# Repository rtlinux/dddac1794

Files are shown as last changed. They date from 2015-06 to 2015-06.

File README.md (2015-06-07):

# dddac1794
Eagle PCB files for the [DDDAC1794](http://www.dddac.com/dddac1794.html).

The motherboard designed by Doede Douma is very large and uses excessive amounts of space.

My design was made in order to keep the cost of the PCBs down and make it easier to produce the PCBs by hand.

## I2S Data Shifter

[OSH Park project](https://oshpark.com/shared_projects/d8tB1U43).

[Mouser project](http://www.mouser.com/ProjectManager/ProjectDetail.aspx?AccessID=fa918c21fc).

### BOM

- C1-C6: Vishay 100nF 63V
- C7: Nichicon KZ Muse 470uF 25V
- C8: Nichicon KZ Muse 47uF 25V
- IT1: ST LF33CV
- IC1-IC5: Fairchild 74VHC164MX

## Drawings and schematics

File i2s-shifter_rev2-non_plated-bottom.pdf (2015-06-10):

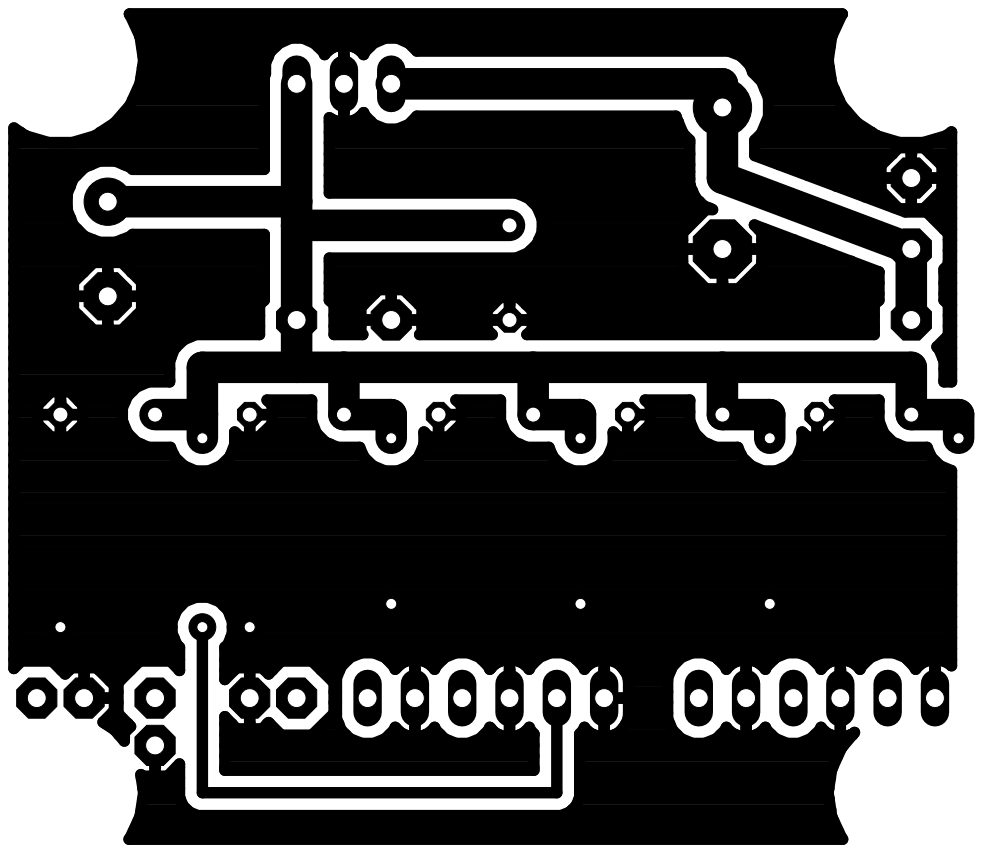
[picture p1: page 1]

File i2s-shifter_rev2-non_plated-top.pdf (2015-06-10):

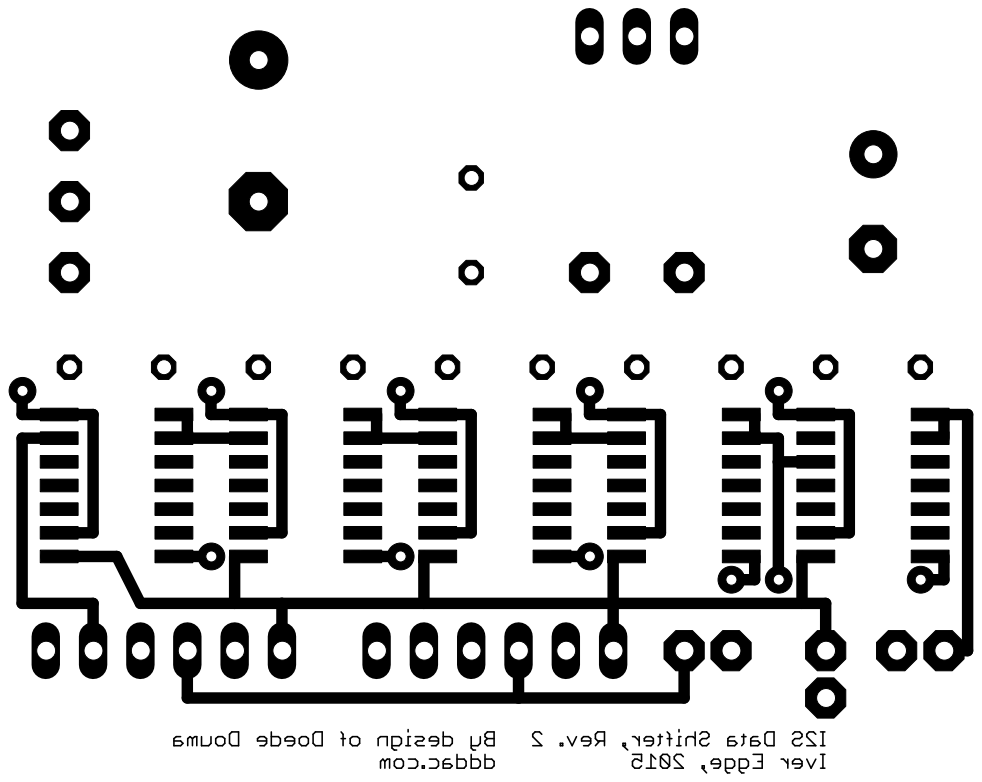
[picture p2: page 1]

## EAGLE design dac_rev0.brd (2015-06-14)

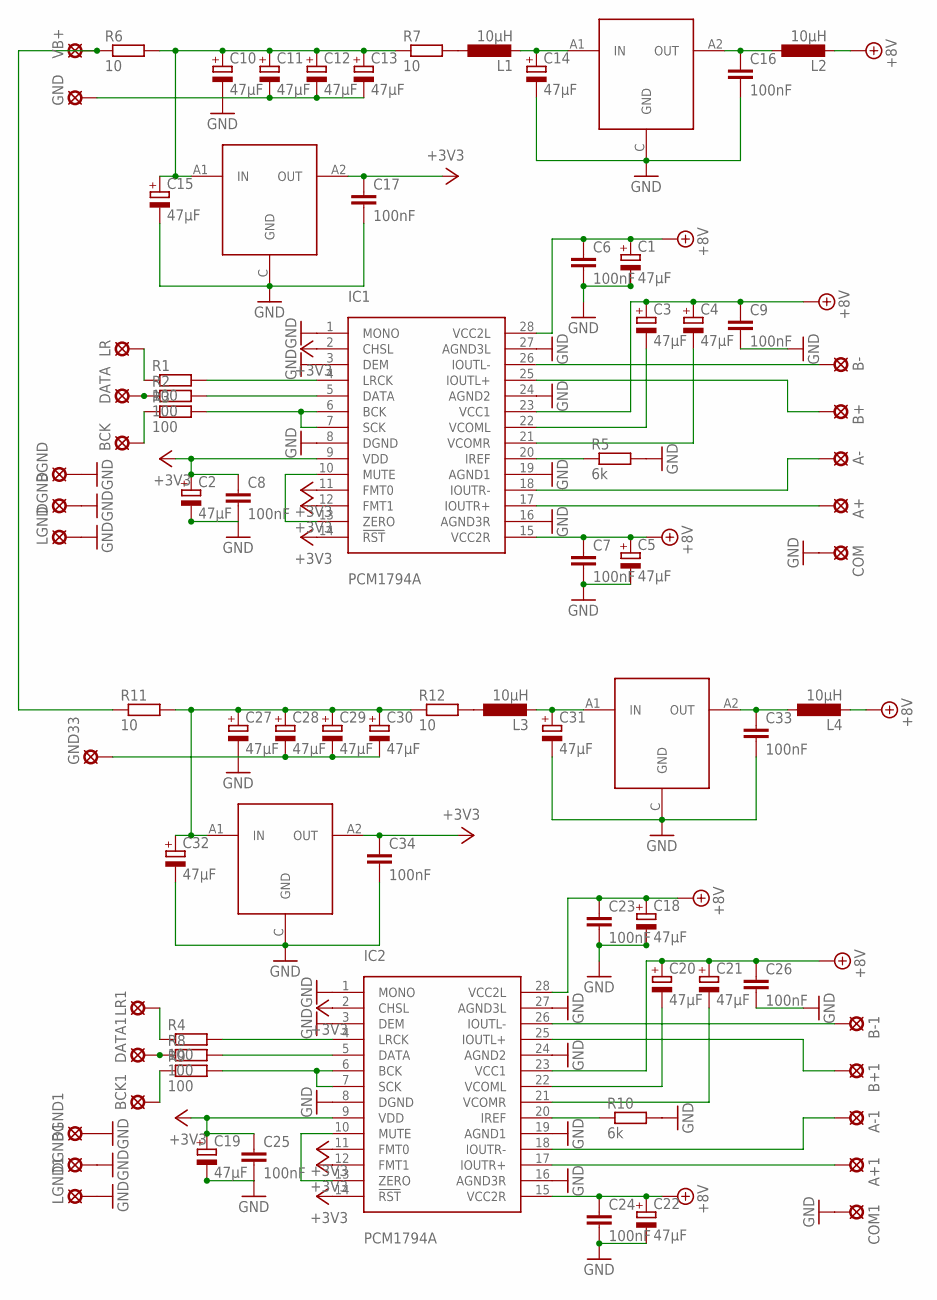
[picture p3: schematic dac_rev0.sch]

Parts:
A+, A+1: LSP10
A-, A-1: LSP10
B+, B+1: LSP10
B-, B-1: LSP10
BCK, BCK1: LSP10
BGND, BGND1: LSP10
C1, C2, C3, C4, C5, C10, C11, C12, C13, C14, C15, C18, C19, C20, C21, C22, C27, C28, C29, C30, C31, C32: 47µF; E5-10,5
C6, C7, C8, C9, C16, C17, C23, C24, C25, C26, C33, C34: 100nF; C050-025X075
COM, COM1: LSP10
DATA, DATA1: LSP10
DGND, DGND1: LSP10
GND, GND33: LSP10
IC1, IC2: PCM1794A; SSOP28
L1, L2, L3, L4: 10μH; 0207/10
LF1, LF33: LF33ABDT-TR; DPACK_3
LF2, LF80: LF80ABDT-TR; DPACK_3
LGND, LGND1: LSP10
LR, LR1: LSP10
R1, R2, R3, R4, R8, R9: 100; 0204/5
R5, R10: 6k; 0204/5
R6, R7, R11, R12: 10; 0204/7
VB+: LSP10

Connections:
+3V3: C2.+, C8.1, C17.1, C19.+, C25.1, C34.1, IC1.2 (CHSL), IC1.9 (VDD), IC1.11 (FMT0), IC1.12 (FMT1), IC1.14 (!RST), IC2.2 (CHSL), IC2.9 (VDD), IC2.11 (FMT0), IC2.12 (FMT1), IC2.14 (!RST), LF1.A2 (OUT), LF33.A2 (OUT)
+8V: C1.+, C3.+, C4.+, C5.+, C6.1, C7.1, C9.1, C18.+, C20.+, C21.+, C22.+, C23.1, C24.1, C26.1, IC1.15 (VCC2R), IC1.23 (VCC1), IC1.28 (VCC2L), IC2.15 (VCC2R), IC2.23 (VCC1), IC2.28 (VCC2L), L2.2, L4.2
GND: BGND.MP, BGND1.MP, C1.-, C2.-, C5.-, C6.2, C7.2, C8.2, C9.2, C10.-, C11.-, C12.-, C13.-, C14.-, C15.-, C16.2, C17.2, C18.-, C19.-, C22.-, C23.2, C24.2, C25.2, C26.2, C27.-, C28.-, C29.-, C30.-, C31.-, C32.-, C33.2, C34.2, COM.MP, COM1.MP, DGND.MP, DGND1.MP, GND.MP, GND33.MP, IC1.1 (MONO), IC1.3 (DEM), IC1.8 (DGND), IC1.16 (AGND3R), IC1.19 (AGND1), IC1.24 (AGND2), IC1.27 (AGND3L), IC2.1 (MONO), IC2.3 (DEM), IC2.8 (DGND), IC2.16 (AGND3R), IC2.19 (AGND1), IC2.24 (AGND2), IC2.27 (AGND3L), LF1.C (GND), LF2.C (GND), LF33.C (GND), LF80.C (GND), LGND.MP, LGND1.MP, R5.2, R10.2
unnamed: IC1.10 (MUTE), IC1.13 (ZERO)
unnamed: BCK.MP, R3.1
unnamed: DATA.MP, R2.1
unnamed: IC1.4 (LRCK), R1.2
unnamed: IC1.6 (BCK), IC1.7 (SCK), R3.2
unnamed: IC1.20 (IREF), R5.1
unnamed: LR.MP, R1.1
unnamed: IC1.5 (DATA), R2.2
unnamed: B-.MP, IC1.26 (IOUTL-)
unnamed: B+.MP, IC1.25 (IOUTL+)
unnamed: A-.MP, IC1.18 (IOUTR-)
unnamed: A+.MP, IC1.17 (IOUTR+)
unnamed: C3.-, IC1.22 (VCOML)
unnamed: C4.-, IC1.21 (VCOMR)
unnamed: C10.+, C11.+, C12.+, C13.+, C15.+, LF33.A1 (IN), R6.2, R7.1
unnamed: L1.1, R7.2
unnamed: IC2.10 (MUTE), IC2.13 (ZERO)
unnamed: C14.+, L1.2, LF80.A1 (IN)
unnamed: DATA1.MP, R8.1
unnamed: IC2.4 (LRCK), R4.2
unnamed: C16.1, L2.1, LF80.A2 (OUT)
unnamed: IC2.6 (BCK), IC2.7 (SCK), R9.2
unnamed: IC2.20 (IREF), R10.1
unnamed: LR1.MP, R4.1
unnamed: B-1.MP, IC2.26 (IOUTL-)
unnamed: B+1.MP, IC2.25 (IOUTL+)
unnamed: A-1.MP, IC2.18 (IOUTR-)
unnamed: A+1.MP, IC2.17 (IOUTR+)
unnamed: C20.-, IC2.22 (VCOML)
unnamed: C21.-, IC2.21 (VCOMR)
unnamed: C27.+, C28.+, C29.+, C30.+, C32.+, LF1.A1 (IN), R11.2, R12.1
unnamed: C31.+, L3.2, LF2.A1 (IN)
unnamed: C33.1, L4.1, LF2.A2 (OUT)
unnamed: R6.1, R11.1, VB+.MP
unnamed: L3.1, R12.2
unnamed: BCK1.MP, R9.1
unnamed: IC2.5 (DATA), R8.2

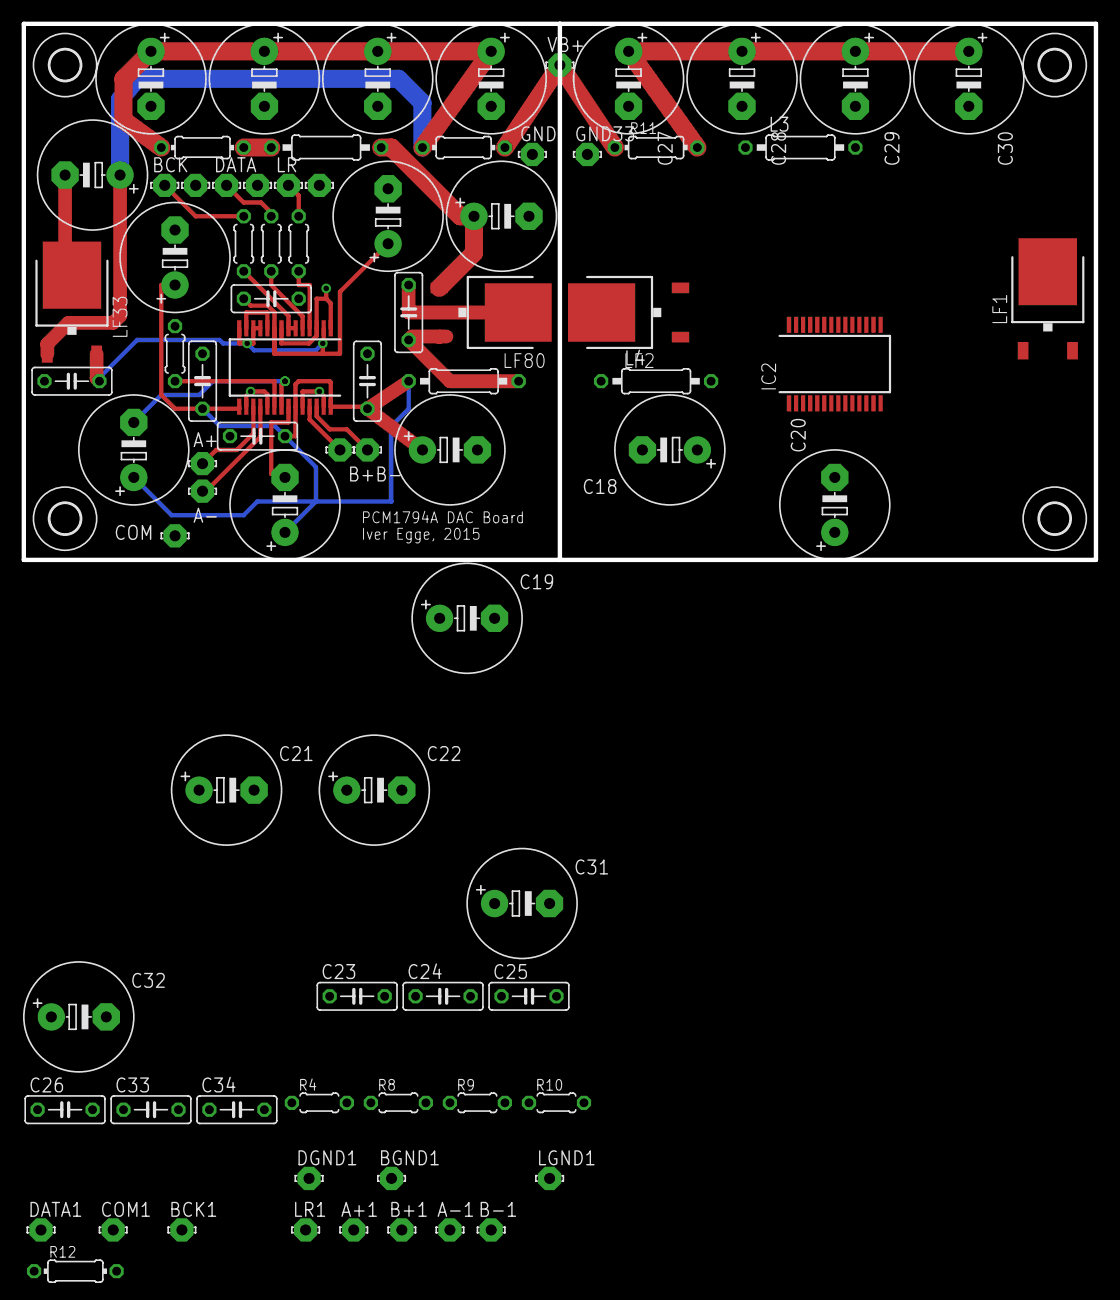
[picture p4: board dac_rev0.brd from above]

Board: 2 copper layers, 99.1 x 49.5 mm, 85 parts (0 on the bottom side), 40 nets.

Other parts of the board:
U$3, U$4, U$5, U$6: 2,8

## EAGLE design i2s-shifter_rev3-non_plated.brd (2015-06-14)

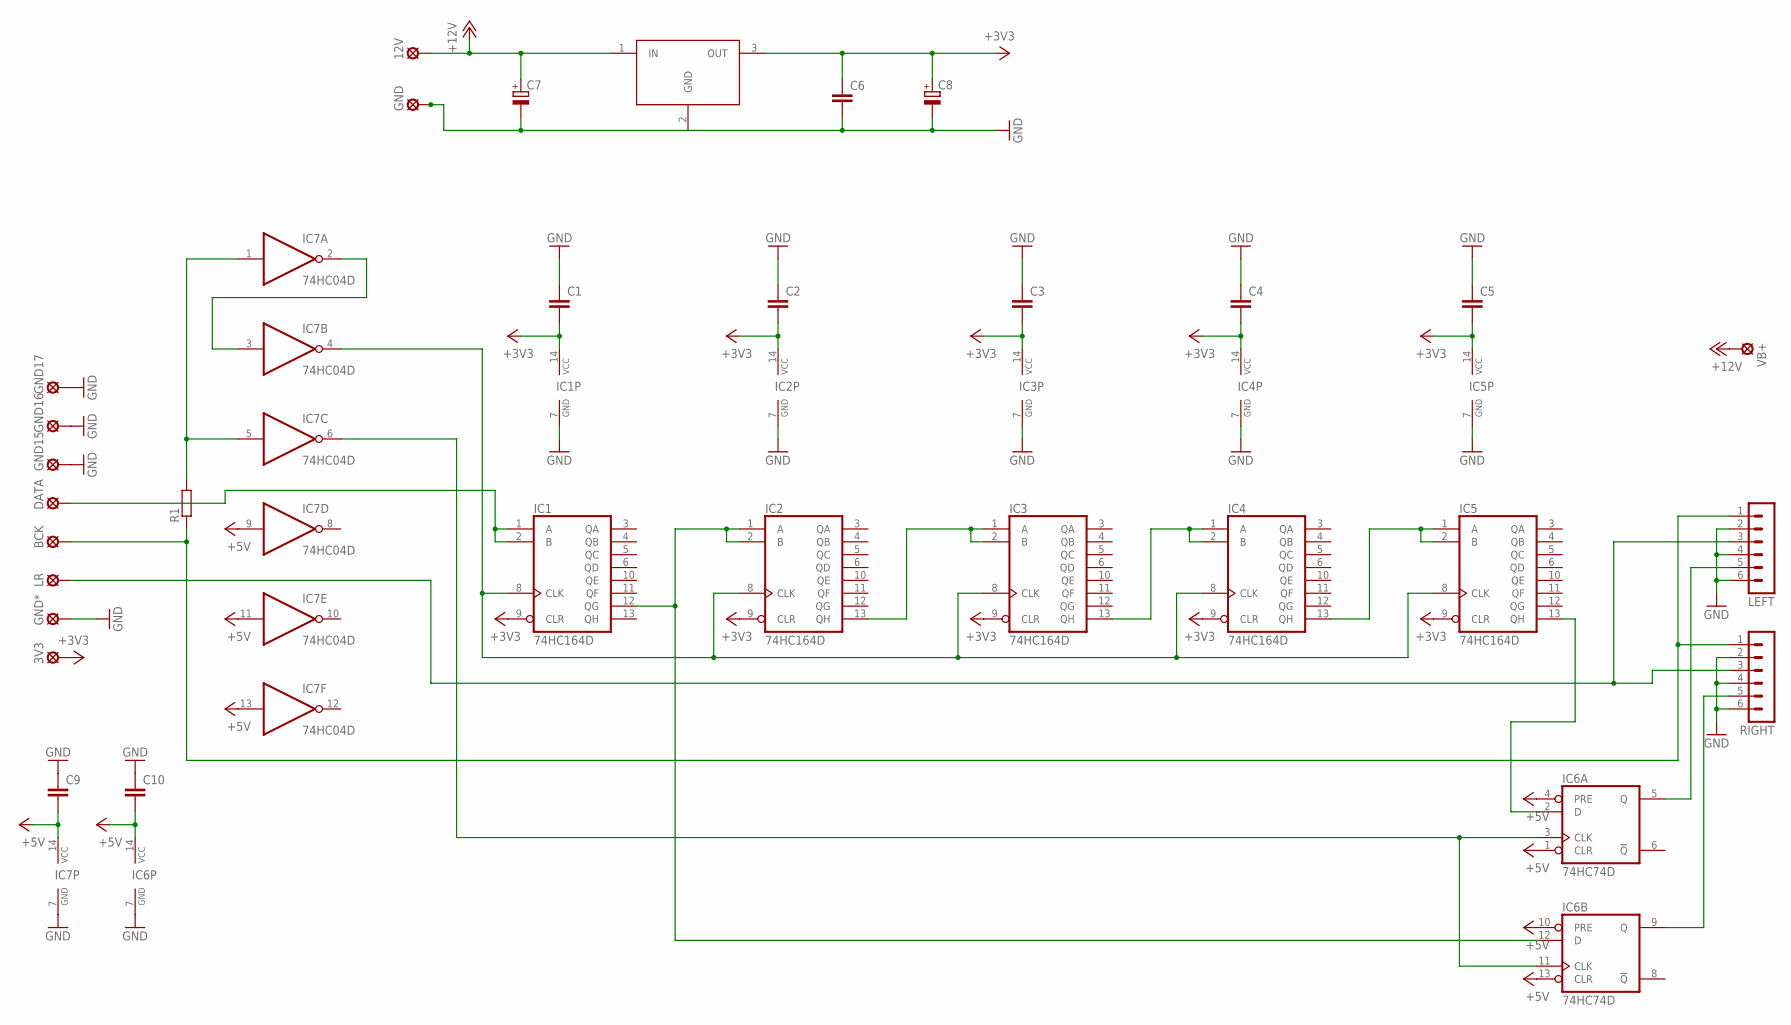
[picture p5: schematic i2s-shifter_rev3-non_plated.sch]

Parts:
3V3, 12V: LSP10
BCK: LSP10
C1, C2, C3, C4, C5, C6, C9, C10: C-EU050-025X075; C050-025X075
C7: CPOL-EUE7.5-16; E7,5-16
C8: CPOL-EUE5-10.5; E5-10,5
DATA: LSP10
GND, GND15, GND16, GND17: LSP10
GND*: LSP10
IC1, IC2, IC3, IC4, IC5: 74HC164D; SO14
IC6: 74HC74D; SO14
IC7: 74HC04D; SO14
IT1: LM3940IT-3.3; TO220V
LEFT: MA06-1
LR: LSP10
R1: R-EU_0204/5; 0204/5
RIGHT: MA06-1
VB+: LSP10

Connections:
+3V3: 3V3.MP, C1.2, C2.2, C3.2, C4.2, C5.2, C6.1, C8.+, IC1.9 (CLR), IC1.14 (VCC), IC2.9 (CLR), IC2.14 (VCC), IC3.9 (CLR), IC3.14 (VCC), IC4.9 (CLR), IC4.14 (VCC), IC5.9 (CLR), IC5.14 (VCC), IT1.3 (OUT)
+5V: C9.2, C10.2, IC6.1 (CLR), IC6.4 (PRE), IC6.10 (PRE), IC6.13 (CLR), IC6.14 (VCC), IC7.9 (I), IC7.11 (I), IC7.13 (I), IC7.14 (VCC)
+12V: 12V.MP, C7.+, IT1.1 (IN), VB+.MP
GND: C1.1, C2.1, C3.1, C4.1, C5.1, C6.2, C7.-, C8.-, C9.1, C10.1, GND.MP, GND15.MP, GND16.MP, GND17.MP, GND*.MP, IC1.7 (GND), IC2.7 (GND), IC3.7 (GND), IC4.7 (GND), IC5.7 (GND), IC6.7 (GND), IC7.7 (GND), IT1.2 (GND), LEFT.2, LEFT.4, LEFT.6, RIGHT.2, RIGHT.4, RIGHT.6
unnamed: DATA.MP, IC1.1 (A), IC1.2 (B)
unnamed: IC1.8 (CLK), IC2.8 (CLK), IC3.8 (CLK), IC4.8 (CLK), IC5.8 (CLK), IC7.4 (O)
unnamed: IC5.13 (QH), IC6.2 (D)
unnamed: IC2.13 (QH), IC3.1 (A), IC3.2 (B)
unnamed: IC3.13 (QH), IC4.1 (A), IC4.2 (B)
unnamed: IC4.13 (QH), IC5.1 (A), IC5.2 (B)
unnamed: IC6.5 (Q), LEFT.5
unnamed: IC6.9 (Q), RIGHT.5
unnamed: LEFT.3, LR.MP, RIGHT.3
unnamed: BCK.MP, LEFT.1, R1.1, RIGHT.1
unnamed: IC7.2 (O), IC7.3 (I)
unnamed: IC6.3 (CLK), IC6.11 (CLK), IC7.6 (O)
unnamed: IC1.12 (QG), IC2.1 (A), IC2.2 (B), IC6.12 (D)
unnamed: IC7.1 (I), IC7.5 (I), R1.2

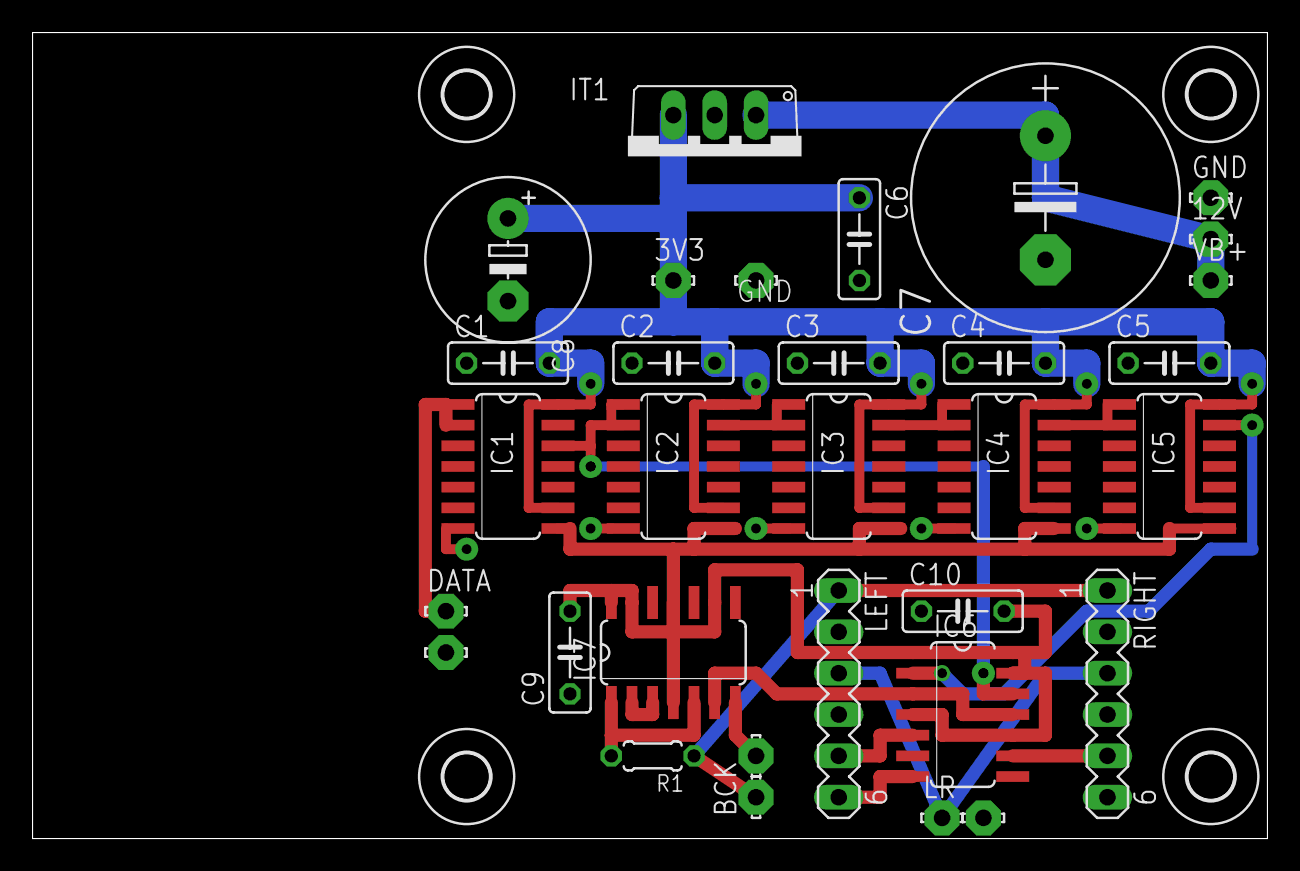
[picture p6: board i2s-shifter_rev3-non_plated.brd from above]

Board: 2 copper layers, 75.9 x 49.5 mm, 36 parts (0 on the bottom side), 18 nets.

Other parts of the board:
U$1, U$2, U$3, U$4: 2,8

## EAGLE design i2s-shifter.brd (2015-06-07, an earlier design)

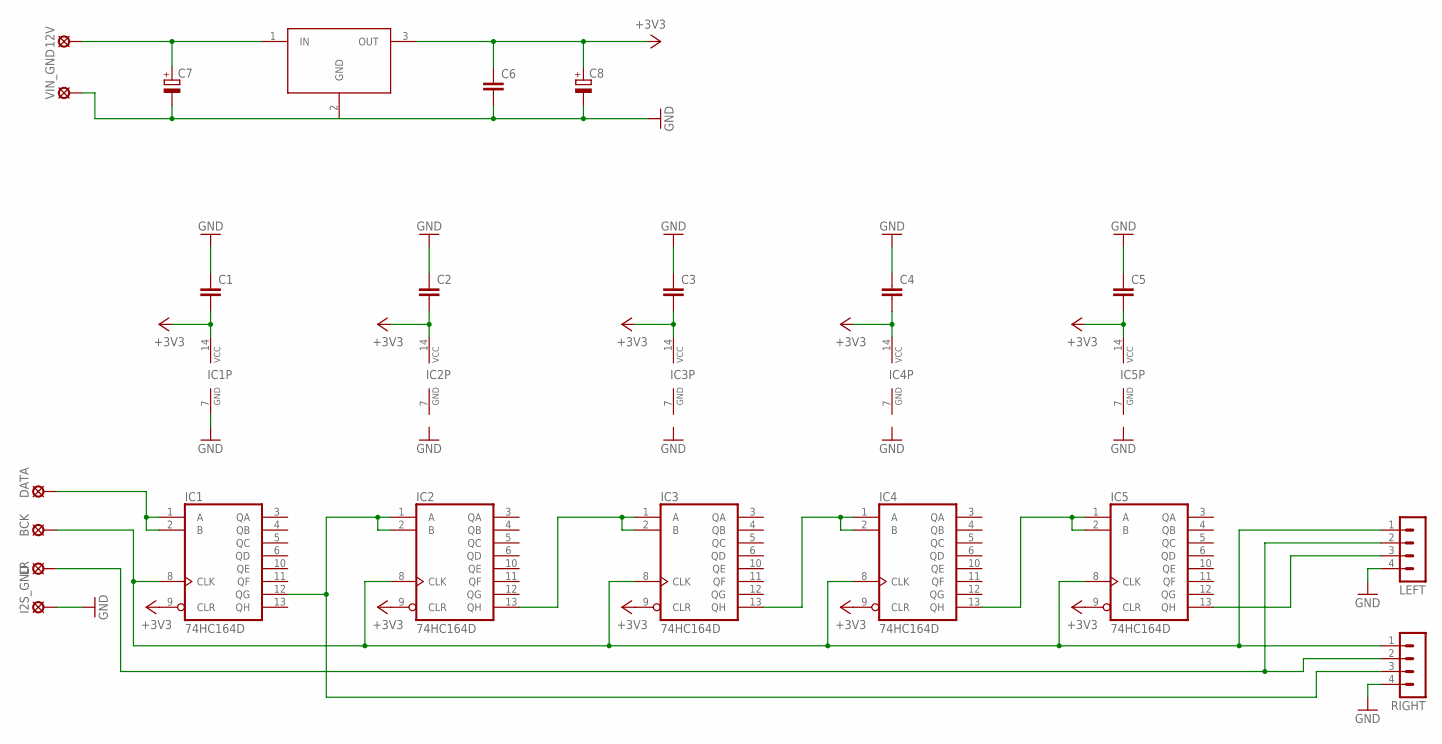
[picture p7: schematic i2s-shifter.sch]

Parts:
12V: LSP10
BCK: LSP10
C1, C2, C3, C4, C5, C6: C-EU050-025X075; C050-025X075
C7: CPOL-EUE7.5-16; E7,5-16
C8: CPOL-EUE5-10.5; E5-10,5
DATA: LSP10
I2S_GND: LSP10
IC1, IC2, IC3, IC4, IC5: 74HC164D; SO14
IT1: LM3940IT-3.3; TO220V
LEFT: MA04-1
LR: LSP10
RIGHT: MA04-1
VIN_GND: LSP10

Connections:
+3V3: C1.2, C2.2, C3.2, C4.2, C5.2, C6.1, C8.+, IC1.9 (CLR), IC1.14 (VCC), IC2.9 (CLR), IC2.14 (VCC), IC3.9 (CLR), IC3.14 (VCC), IC4.9 (CLR), IC4.14 (VCC), IC5.9 (CLR), IC5.14 (VCC), IT1.3 (OUT)
unnamed: DATA.MP, IC1.1 (A), IC1.2 (B)
unnamed: BCK.MP, IC1.8 (CLK), IC2.8 (CLK), IC3.8 (CLK), IC4.8 (CLK), IC5.8 (CLK), LEFT.1, RIGHT.1
unnamed: IC1.12 (QG), IC2.1 (A), IC2.2 (B), RIGHT.3
unnamed: IC2.13 (QH), IC3.1 (A), IC3.2 (B)
unnamed: IC3.13 (QH), IC4.1 (A), IC4.2 (B)
unnamed: IC4.13 (QH), IC5.1 (A), IC5.2 (B)
unnamed: LEFT.2, LR.MP, RIGHT.2
unnamed: IC5.13 (QH), LEFT.3
unnamed: 12V.MP, C7.+, IT1.1 (IN)
NS999: C1.1, C2.1, C3.1, C4.1, C5.1, C6.2, C7.-, C8.-, I2S_GND.MP, IC1.7 (GND), IC2.7 (GND), IC3.7 (GND), IC4.7 (GND), IC5.7 (GND), IT1.2 (GND), LEFT.4, RIGHT.4, VIN_GND.MP

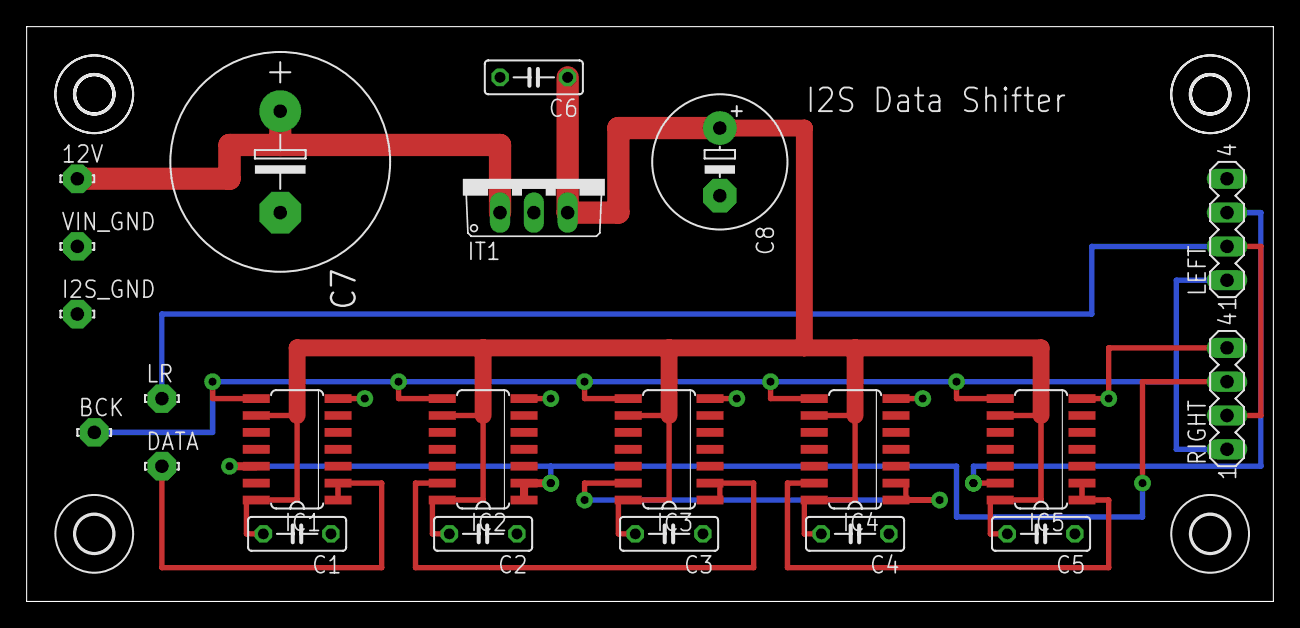
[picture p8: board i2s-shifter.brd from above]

Board: 2 copper layers, 93.7 x 43.2 mm, 28 parts (0 on the bottom side), 11 nets.

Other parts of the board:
U$1, U$2, U$3, U$4, U$5, U$6: 2,8

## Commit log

2015-06-06 i2s shifter board
    [i2s-shifter.brd, i2s-shifter.sch]
2015-06-07 moved caps closer to vcc
    [i2s-shifter.brd, i2s-shifter.sch]
2015-06-07 rev1. much better arrangment of components. shorter signal paths
    [i2s-shifter_rev1.brd, i2s-shifter_rev1.sch]
2015-06-07 rev2. made board smaller than 100x50mm
    [i2s-shifter_rev2.brd, i2s-shifter_rev2.sch]
2015-06-08 through hole components soldered only on bottom layer. ground pads for twisted wiring
    [i2s-shifter_rev2-non_plated.brd, i2s-shifter_rev2-non_plated.sch]
2015-06-14 wip dac board. added libs
    [dac_rev0.brd, dac_rev0.sch, i2s-shifter_rev2-non_plated.sch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]
2015-06-14 minor tweak
    [dac_rev0.brd]
